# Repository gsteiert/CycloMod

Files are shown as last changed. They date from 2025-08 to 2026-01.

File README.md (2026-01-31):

# CycloMod
Cyclone 10LP plus RP2350 in SparkFun MicroMod form-factor

Be sure to subscribe to the [Cyclomod Crowd Supply Campaign](https://www.crowdsupply.com/steiert-solutions/cyclomod) for updates on when and how to get CycloMod.

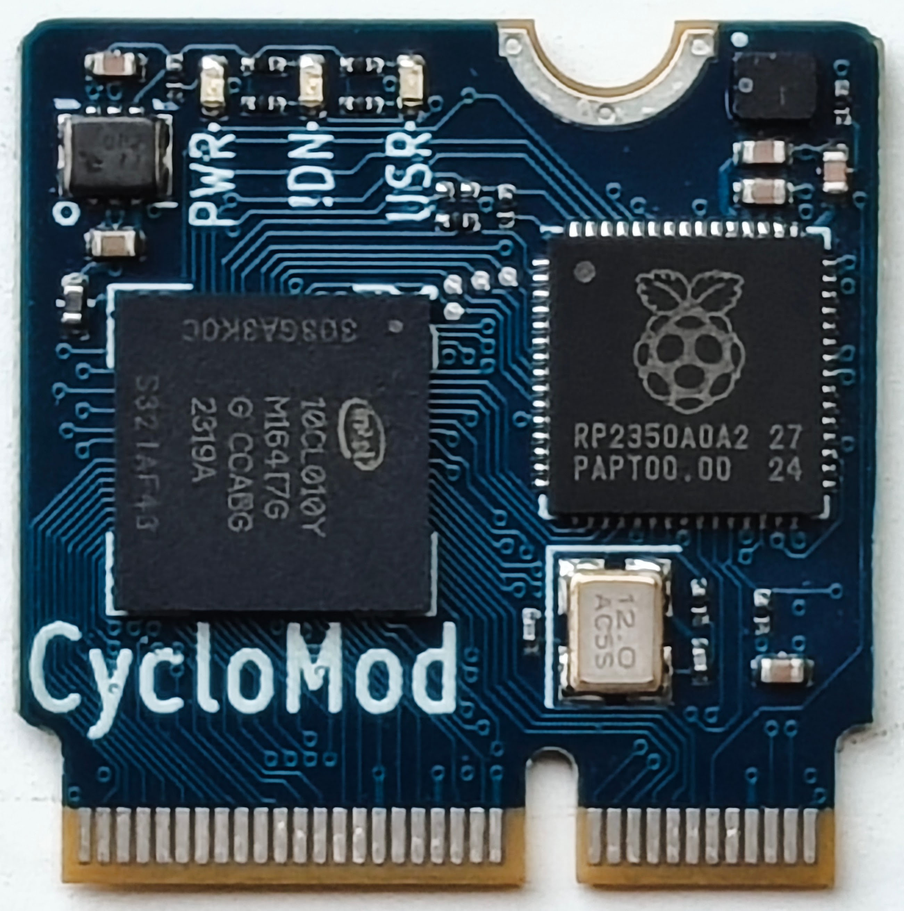
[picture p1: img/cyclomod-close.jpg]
CycloMod Board


CycloMod brings the flexibility of an FPGA to the SparkFun MicroMod ecosystem.  It combines the Raspberry Pi RP2350 with the Altera Cyclone 10LP, in a compact, adaptable module.  

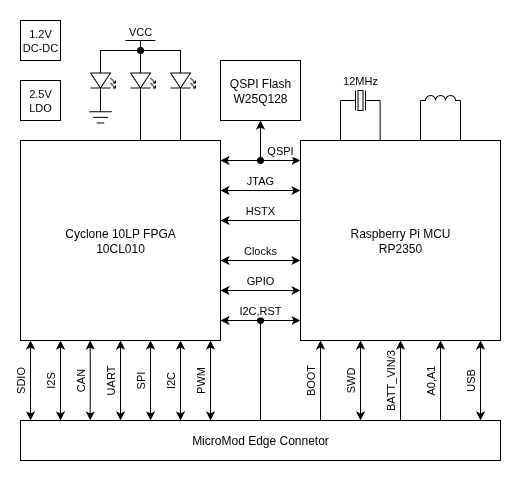
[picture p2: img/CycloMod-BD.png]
CycloMod Block Diagram


The FPGA and MCU are designed to be used together.  Most of the MicroMod I/O are connected to the FPGA for highest flexibility, while some functions like USB, ADC and SWD take advantage of the dedicated peripherals in the RP2350.  A few signals, like reset and the primary I2C bus, are connected to both devices.

Most of the RP2350 I/O are connected to Cyclone 10LP.  The MCU is connected to the JTAG pins of the FPGA so that the same flash can store the MCU firmware and FPGA images to be loaded with the Altera JBC player.  GPIO on the FPGA are connected to the MCU QSPI interface to provide a reasonable speed data path between the two devices.  The HSTX port is also connected for higher speed streaming from the MCU to the FPGA.  Input and Output clocks are also connected between the two devices to allow for sharing the 12MHz refernce crystal from the MCU and PLLs in the FPGA.  

The primary intended use case is for the RP2350 to manage the loading of the FPGA to eliminate the need for an additional storage device.  The active serial configuration pins are connected to the SPI port pins on the MicroMod card edge and there is a solder bridge selector that can be cut and shorted to enable laoding the FPGA from external SPI flash.

FPGA images can be transfered to flash over USB using the UF2 flash loader built into the RP2350 ROM.  Altera provides a [JAM Byte Code player](https://github.com/steieio/altera-jbc-player) that can be used to load the FPGA over JTAG.  A [script is available to combine the JBC file with the RP2350 firmware in a single UF2 file](https://github.com/steieio/jbcuf2).  This methodology was demonstrated in the ["Build a $5 FPGA loader" workshop at Crowd Supply Teardown 2024](https://www.crowdsupply.com/teardown/portland-2024/workshop/build-a-5-fpga-loader).

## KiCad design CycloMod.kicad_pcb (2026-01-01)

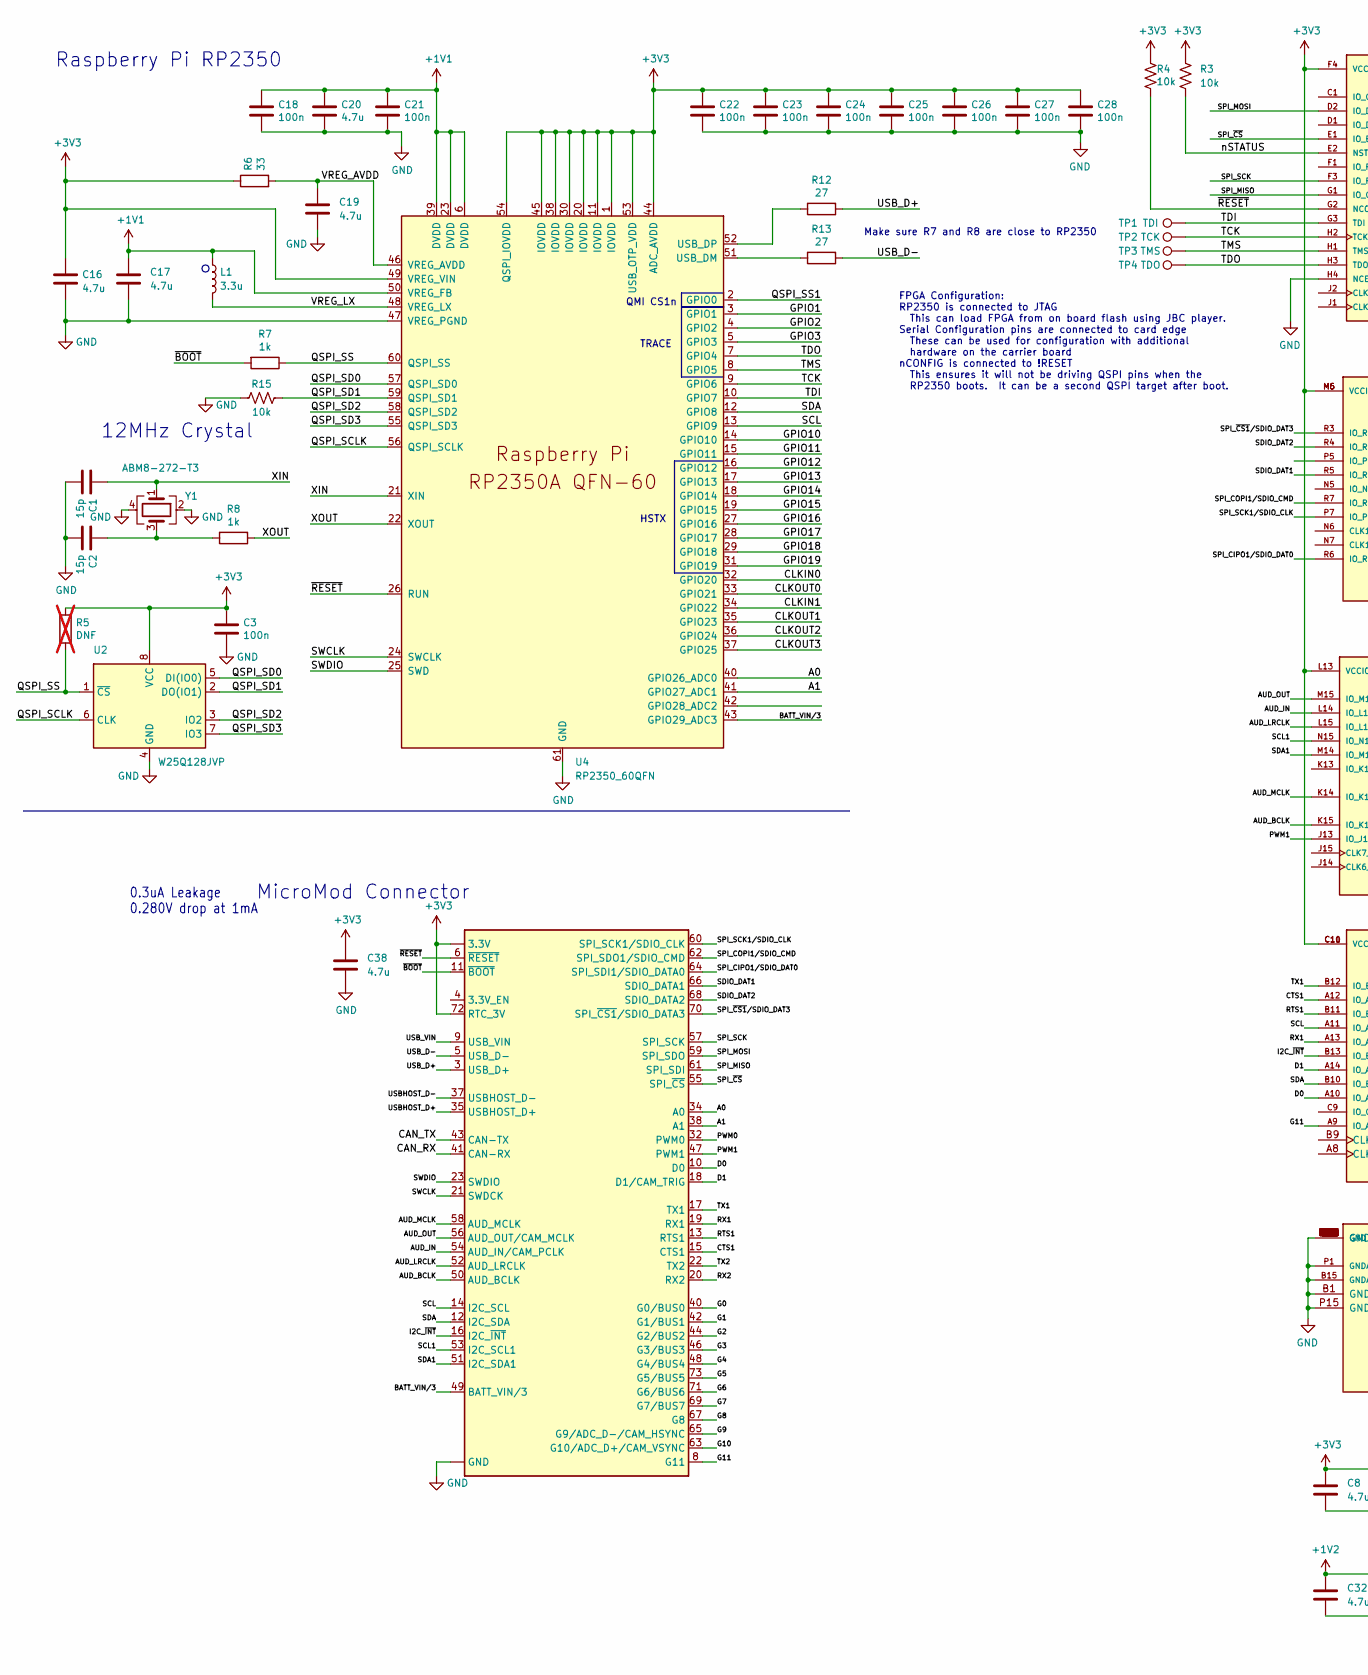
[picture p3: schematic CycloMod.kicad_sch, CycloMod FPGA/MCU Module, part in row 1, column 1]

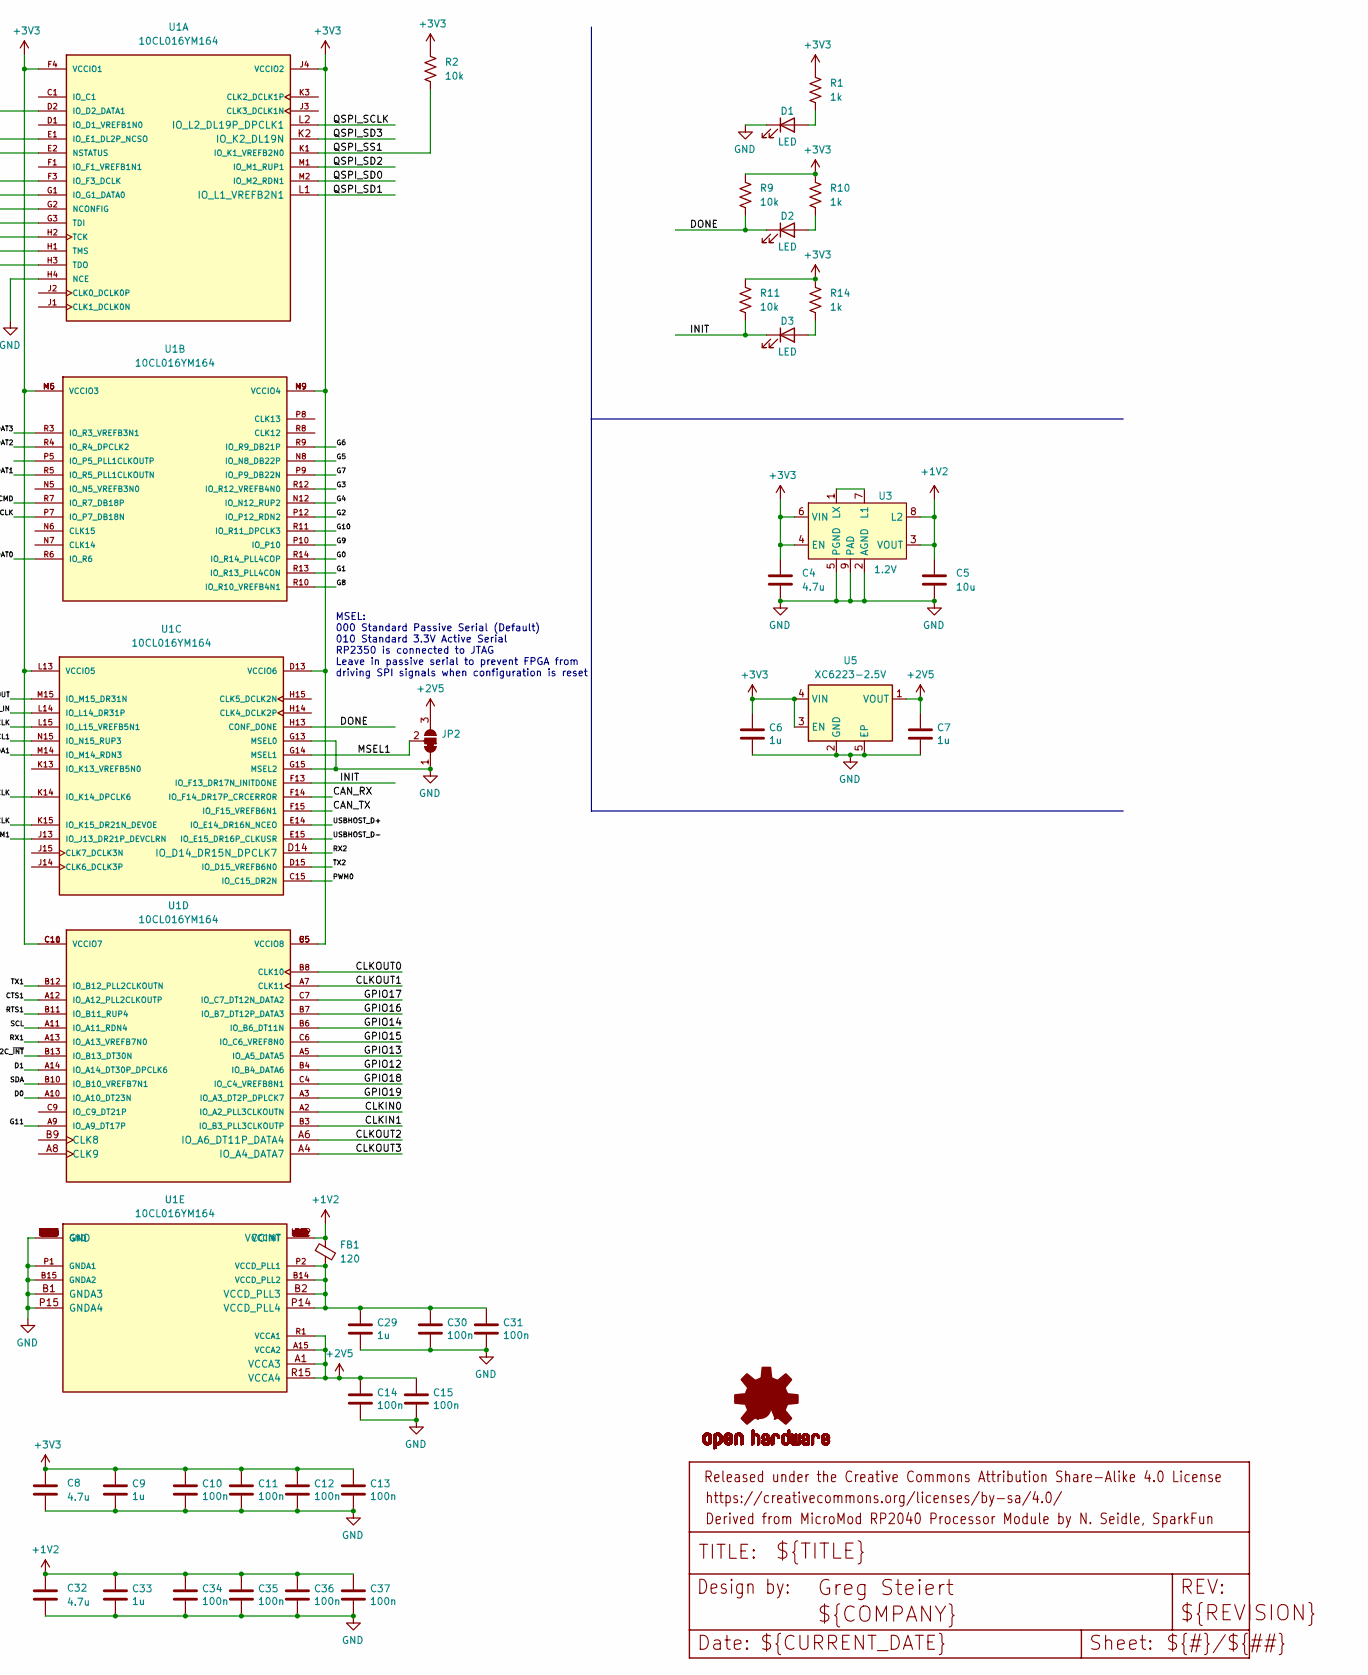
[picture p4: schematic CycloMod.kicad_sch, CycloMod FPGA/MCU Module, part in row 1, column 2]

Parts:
C1, C2: 15p; C_0201_0603Metric; MPN CC0201JRNPO9BN150; LCSC C277480
C3, C10, C11, C12, C13, C14, C15, C18, C21, C22, C23, C24, C25, C26, C27, C28, C30, C31, C34, C35, C36, C37: 100n; C_0201_0603Metric; MPN GRM033R61A104KE15D; LCSC C76934
C4, C8, C19, C20, C32, C38: 4.7u; C_0402_1005Metric; MPN CL05A475MQ5NRNC; LCSC C307423
C5: 10u; C_0402_1005Metric; MPN CL05A106MQ5NUNC; LCSC C15525
C6, C7, C9, C29, C33: 1u; C_0402_1005Metric; MPN CL05A105KP5NNNC; LCSC C14445
C16, C17: 4.7u; C_0402_1005Metric_small_pads; MPN CL05A475MQ5NRNC; LCSC C307423
D1, D2, D3: LED; LED_0402_1005Metric; MPN IN-S42BT5B; LCSC C6968967
FB1: 120; R_0402_1005Metric; MPN BLM15AG121SN1D; LCSC C85812
FRAME1: FRAME-LEDGER; CREATIVE_COMMONS
J1: MICROMOD-2222; MicroMod_Processor
JP2: SolderJumper_3_Bridged12; SolderJumper-3pin_Bridged_RoundedPad_0402
L1: 3.3u; L_pol_2016; MPN AOTA-B201610S3R3-101-T; LCSC C42411119
LOGO3: OSHW-LOGOMINI; OSHW-LOGO-MINI
R1, R7, R8, R10, R14: 1k; R_0201_0603Metric; MPN RC0201FR-071KL; LCSC C138165
R2, R3, R4, R9, R11, R15: 10k; R_0201_0603Metric; MPN RC0201FR-0710KL; LCSC C106225
R5: DNF; R_0201_0603Metric; not fitted
R6: 33; R_0201_0603Metric; MPN RC0201FR-0733RL; LCSC C295794
R12, R13: 27; R_0201_0603Metric; MPN RC0201FR-0727RL; LCSC C273268
TP1: TDI; TestPoint_Pad_D0.5mm
TP2: TCK; TestPoint_Pad_D0.5mm
TP3: TMS; TestPoint_Pad_D0.5mm
TP4: TDO; TestPoint_Pad_D0.5mm
U1: 10CL016YM164; M164_8.0x8.0mm_0.5mm; PARTREV 2019.03.29; LCSC C6063581
U2: W25Q128JVP; WSON-8-1EP_6x5mm_P1.27mm_EP3.4x4.3mm; MPN W25Q128JVPIQ; LCSC C190862
U3: 1.2V; CL-2025-02; MPN XCL239B123FR-G; LCSC C6036085
U4: RP2350_60QFN; RP2350-QFN-60-1EP_7x7_P0.4mm_EP3.4x3.4mm_ThermalVias; MPN RP2350A; LCSC C42411118
U5: XC6223-2.5V; UDFN-4-1EP_1x1mm_P0.65mm_EP0.48x0.48mm; MPN XC6233H2519R-G; LCSC C6934286
Y1: ABM8-272-T3; Crystal_SMD_3225-4Pin_3.2x2.5mm; MPN ABM8-272-T3; LCSC C20625731

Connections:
+1V1: C17.1, C18.1, C20.1, C21.1, L1.1, U4.6 (DVDD), U4.23 (DVDD), U4.39 (DVDD), U4.50 (VREG_FB)
+1V2: C5.1, C32.1, C33.1, C34.1, C35.1, C36.1, C37.1, FB1.1, U1.D3 (VCCINT), U1.D6 (VCCINT), U1.D8 (VCCINT), U1.D10 (VCCINT), U1.F12 (VCCINT), U1.H12 (VCCINT), U1.K12 (VCCINT), U1.L3 (VCCINT), U1.M8 (VCCINT), U1.M11 (VCCINT), U1.N2 (VCCINT), U1.P3 (VCCINT), U3.3 (VOUT), U3.8 (L2)
+2V5: C7.1, C14.1, C15.1, JP2.3 (B), U1.A1 (VCCA3), U1.A15 (VCCA2), U1.R1 (VCCA1), U1.R15 (VCCA4), U5.1 (VOUT)
+3V3: C3.1, C4.1, C6.1, C8.1, C9.1, C10.1, C11.1, C12.1, C13.1, C16.1, C22.1, C23.1, C24.1, C25.1, C26.1, C27.1, C28.1, C38.1, J1.2 (3.3V), J1.72 (RTC_3V), J1.74 (3.3V), R1.1, R2.1, R3.1, R4.1, R5.1, R6.1, R9.1, R10.1, R11.1, R14.1, U1.B5 (VCCIO8), U1.C5 (VCCIO8), U1.C10 (VCCIO7), U1.C11 (VCCIO7), U1.D13 (VCCIO6), U1.F4 (VCCIO1), U1.J4 (VCCIO2), U1.L13 (VCCIO5), U1.M5 (VCCIO3), U1.M6 (VCCIO3), U1.M9 (VCCIO4), U1.N9 (VCCIO4), U2.8 (VCC), U3.4 (EN), U3.6 (VIN), U4.1 (IOVDD), U4.11 (IOVDD), U4.20 (IOVDD), U4.30 (IOVDD), U4.38 (IOVDD), U4.44 (ADC_AVDD), U4.45 (IOVDD), U4.49 (VREG_VIN), U4.53 (USB_OTP_VDD), U4.54 (QSPI_IOVDD), U5.3 (EN), U5.4 (VIN)
/A0: J1.34 (A0), U4.40 (GPIO26_ADC0)
/A1: J1.38 (A1), U4.41 (GPIO27_ADC1)
/AUD_BCLK: J1.50 (AUD_BCLK), U1.K15 (IO_K15_DR21N_DEVOE)
/AUD_IN: J1.54 (AUD_IN/CAM_PCLK), U1.L14 (IO_L14_DR31P)
/AUD_LRCLK: J1.52 (AUD_LRCLK), U1.L15 (IO_L15_VREFB5N1)
/AUD_MCLK: J1.58 (AUD_MCLK), U1.K14 (IO_K14_DPCLK6)
/AUD_OUT: J1.56 (AUD_OUT/CAM_MCLK), U1.M15 (IO_M15_DR31N)
/BATT_VIN/3: J1.49 (BATT_VIN/3), U4.43 (GPIO29_ADC3)
/CAN_RX: J1.41 (CAN-RX), U1.F14 (IO_F14_DR17P_CRCERROR)
/CAN_TX: J1.43 (CAN-TX), U1.F15 (IO_F15_VREFB6N1)
/CLKIN0: U1.A2 (IO_A2_PLL3CLKOUTN), U4.32 (GPIO20)
/CLKIN1: U1.B3 (IO_B3_PLL3CLKOUTP), U4.34 (GPIO22)
/CLKOUT0: U1.B8 (CLK10), U4.33 (GPIO21)
/CLKOUT1: U1.A7 (CLK11), U4.35 (GPIO23)
/CLKOUT2: U1.A6 (IO_A6_DT11P_DATA4), U4.36 (GPIO24)
/CLKOUT3: U1.A4 (IO_A4_DATA7), U4.37 (GPIO25)
/CTS1: J1.15 (CTS1), U1.A12 (IO_A12_PLL2CLKOUTP)
/D0: J1.10 (D0), U1.A10 (IO_A10_DT23N)
/D1: J1.18 (D1/CAM_TRIG), U1.A14 (IO_A14_DT30P_DPCLK6)
/DONE: D2.1 (K), R9.2, U1.H13 (CONF_DONE)
/G0: J1.40 (G0/BUS0), U1.R14 (IO_R14_PLL4COP)
/G1: J1.42 (G1/BUS1), U1.R13 (IO_R13_PLL4CON)
/G2: J1.44 (G2/BUS2), U1.P12 (IO_P12_RDN2)
/G3: J1.46 (G3/BUS3), U1.R12 (IO_R12_VREFB4N0)
/G4: J1.48 (G4/BUS4), U1.N12 (IO_N12_RUP2)
/G5: J1.73 (G5/BUS5), U1.N8 (IO_N8_DB22P)
/G6: J1.71 (G6/BUS6), U1.R9 (IO_R9_DB21P)
/G7: J1.69 (G7/BUS7), U1.P9 (IO_P9_DB22N)
/G8: J1.67 (G8), U1.R10 (IO_R10_VREFB4N1)
/G9: J1.65 (G9/ADC_D-/CAM_HSYNC), U1.P10 (IO_P10)
/G10: J1.63 (G10/ADC_D+/CAM_VSYNC), U1.R11 (IO_R11_DPCLK3)
/G11: J1.8 (G11), U1.A9 (IO_A9_DT17P)
/GPIO1: U4.3 (GPIO1)
/GPIO2: U4.4 (GPIO2)
/GPIO3: U4.5 (GPIO3)
/GPIO10: U4.14 (GPIO10)
/GPIO11: U4.15 (GPIO11)
/GPIO12: U1.B4 (IO_B4_DATA6), U4.16 (GPIO12)
/GPIO13: U1.A5 (IO_A5_DATA5), U4.17 (GPIO13)
/GPIO14: U1.B6 (IO_B6_DT11N), U4.18 (GPIO14)
/GPIO15: U1.C6 (IO_C6_VREF8N0), U4.19 (GPIO15)
/GPIO16: U1.B7 (IO_B7_DT12P_DATA3), U4.27 (GPIO16)
/GPIO17: U1.C7 (IO_C7_DT12N_DATA2), U4.28 (GPIO17)
/GPIO18: U1.C4 (IO_C4_VREFB8N1), U4.29 (GPIO18)
/GPIO19: U1.A3 (IO_A3_DT2P_DPLCK7), U4.31 (GPIO19)
/I2C_~INT: J1.16 (I2C_~INT), U1.B13 (IO_B13_DT30N)
/INIT: D3.1 (K), R11.2, U1.F13 (IO_F13_DR17N_INITDONE)
/MSEL1: JP2.2 (C), U1.G14 (MSEL1)
/PWM0: J1.32 (PWM0), U1.C15 (IO_C15_DR2N)
/PWM1: J1.47 (PWM1), U1.J13 (IO_J13_DR21P_DEVCLRN)
/QSPI_SCLK: U1.L2 (IO_L2_DL19P_DPCLK1), U2.6 (CLK), U4.56 (QSPI_SCLK)
/QSPI_SD0: U1.M2 (IO_M2_RDN1), U2.5 (DI(IO0)), U4.57 (QSPI_SD0)
/QSPI_SD1: R15.2, U1.L1 (IO_L1_VREFB2N1), U2.2 (DO(IO1)), U4.59 (QSPI_SD1)
/QSPI_SD2: U1.M1 (IO_M1_RUP1), U2.3 (IO2), U4.58 (QSPI_SD2)
/QSPI_SD3: U1.K2 (IO_K2_DL19N), U2.7 (IO3), U4.55 (QSPI_SD3)
/QSPI_SS: R5.2, R7.1, U2.1 (~CS), U4.60 (QSPI_SS)
/QSPI_SS1: R2.2, U1.K1 (IO_K1_VREFB2N0), U4.2 (GPIO0)
/RTS1: J1.13 (RTS1), U1.B11 (IO_B11_RUP4)
/RX1: J1.19 (RX1), U1.A13 (IO_A13_VREFB7N0)
/RX2: J1.20 (RX2), U1.D14 (IO_D14_DR15N_DPCLK7)
/SCL: J1.14 (I2C_SCL), U1.A11 (IO_A11_RDN4), U4.13 (GPIO9)
/SCL1: J1.53 (I2C_SCL1), U1.N15 (IO_N15_RUP3)
/SDA: J1.12 (I2C_SDA), U1.B10 (IO_B10_VREFB7N1), U4.12 (GPIO8)
/SDA1: J1.51 (I2C_SDA1), U1.M14 (IO_M14_RDN3)
/SDIO_DAT1: J1.66 (SDIO_DATA1), U1.R5 (IO_R5_PLL1CLKOUTN)
/SDIO_DAT2: J1.68 (SDIO_DATA2), U1.R4 (IO_R4_DPCLK2)
/SPI_CIPO1/SDIO_DAT0: J1.64 (SPI_SDI1/SDIO_DATA0), U1.R6 (IO_R6)
/SPI_COPI1/SDIO_CMD: J1.62 (SPI_SDO1/SDIO_CMD), U1.R7 (IO_R7_DB18P)
/SPI_MISO: J1.61 (SPI_SDI), U1.G1 (IO_G1_DATA0)
/SPI_MOSI: J1.59 (SPI_SDO), U1.D2 (IO_D2_DATA1)
/SPI_SCK: J1.57 (SPI_SCK), U1.F3 (IO_F3_DCLK)
/SPI_SCK1/SDIO_CLK: J1.60 (SPI_SCK1/SDIO_CLK), U1.P7 (IO_P7_DB18N)
/SPI_~CS1/SDIO_DAT3: J1.70 (SPI_~CS1/SDIO_DATA3), U1.R3 (IO_R3_VREFB3N1)
/SPI_~CS: J1.55 (SPI_~CS), U1.E1 (IO_E1_DL2P_NCSO)
/SWCLK: J1.21 (SWDCK), U4.24 (SWCLK)
/SWDIO: J1.23 (SWDIO), U4.25 (SWD)
/TCK: TP2.1, U1.H2 (TCK), U4.9 (GPIO6)
/TDI: TP1.1, U1.G3 (TDI), U4.10 (GPIO7)
/TDO: TP4.1, U1.H3 (TDO), U4.7 (GPIO4)
/TMS: TP3.1, U1.H1 (TMS), U4.8 (GPIO5)
/TX1: J1.17 (TX1), U1.B12 (IO_B12_PLL2CLKOUTN)
/TX2: J1.22 (TX2), U1.D15 (IO_D15_VREFB6N0)
/USBHOST_D+: J1.35 (USBHOST_D+), U1.E14 (IO_E14_DR16N_NCEO)
/USBHOST_D-: J1.37 (USBHOST_D-), U1.E15 (IO_E15_DR16P_CLKUSR)
/USB_D+: J1.3 (USB_D+), R12.1
/USB_D-: J1.5 (USB_D-), R13.1
/USB_VIN: J1.9 (USB_VIN)
/VREG_AVDD: C19.1, R6.2, U4.46 (VREG_AVDD)
/VREG_LX: L1.2, U4.48 (VREG_LX)
/XIN: C1.1, U4.21 (XIN), Y1.1
/XOUT: R8.1, U4.22 (XOUT)
/nSTATUS: R3.2, U1.E2 (NSTATUS)
/~BOOT: J1.11 (~BOOT), R7.2
/~RESET: J1.6 (~RESET), R4.2, U1.G2 (NCONFIG), U4.26 (RUN)
GND: C1.2, C2.2, C3.2, C4.2, C5.2, C6.2, C7.2, C8.2, C9.2, C10.2, C11.2, C12.2, C13.2, C14.2, C15.2, C16.2, C17.2, C18.2, C19.2, C20.2, C21.2, C22.2, C23.2, C24.2, C25.2, C26.2, C27.2, C28.2, C29.2, C30.2, C31.2, C32.2, C33.2, C34.2, C35.2, C36.2, C37.2, C38.2, D1.1 (K), J1.1 (GND), J1.7 (GND), J1.33 (GND), J1.36 (GND), J1.39 (GND), J1.45 (GND), J1.75 (GND), J1.GND, JP2.1 (A), R15.1, U1.B1 (GNDA3), U1.B15 (GNDA2), U1.C2 (GND), U1.C8 (GND), U1.C12 (GND), U1.C14 (GND), U1.D5 (GND), U1.D7 (GND), U1.D9 (GND), U1.D11 (GND), U1.E3 (GND), U1.E13 (GND), U1.F2 (GND), U1.G4 (GND), U1.G12 (GND), U1.G13 (MSEL0), U1.G15 (MSEL2), U1.H4 (NCE), U1.J12 (GND), U1.K4 (GND), U1.M3 (GND), U1.M7 (GND), U1.M10 (GND), U1.M13 (GND), U1.N1 (GND), U1.N4 (GND), U1.N10 (GND), U1.N11 (GND), U1.N14 (GND), U1.P1 (GNDA1), U1.P4 (GND), U1.P6 (GND), U1.P11 (GND), U1.P13 (GND), U1.P15 (GNDA4), U1.R2 (GND), U2.4 (GND), U3.2 (AGND), U3.5 (PGND), U3.9 (PAD), U4.47 (VREG_PGND), U4.61 (GND), U5.2 (GND), U5.5 (EP), Y1.2, Y1.4
unnamed: C2.1, R8.2, Y1.3
unnamed: D1.2 (A), R1.2
unnamed: D2.2 (A), R10.2
unnamed: D3.2 (A), R14.2
unnamed: C29.1, C30.1, C31.1, FB1.2, U1.B2 (VCCD_PLL3), U1.B14 (VCCD_PLL2), U1.P2 (VCCD_PLL1), U1.P14 (VCCD_PLL4)
unnamed: U3.1 (LX), U3.7 (L1)
unnamed: R13.2, U4.51 (USB_DM)
unnamed: R12.2, U4.52 (USB_DP)

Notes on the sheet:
MicroMod Connector
MSEL: 000 Standard Passive Serial (Default) 010 Standard 3.3V Active Serial RP2350 is connected to JTAG Leave in passive serial to prevent FPGA from driving SPI signals when configuration is reset
HSTX
0.3uA Leakage 0.280V drop at 1mA
Raspberry Pi RP2350
QMI CS1n
FPGA Configuration: RP2350 is connected to JTAG This can load FPGA from on board flash using JBC player. Serial Configuration pins are connected to card edge These can be used for configuration with additional hardware on the carrier board nCONFIG is connected to !RESET This ensures it will not be 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
Make sure R7 and R8 are close to RP2350
TRACE
12MHz Crystal

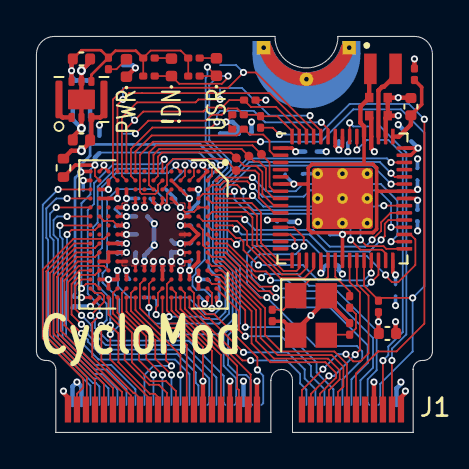
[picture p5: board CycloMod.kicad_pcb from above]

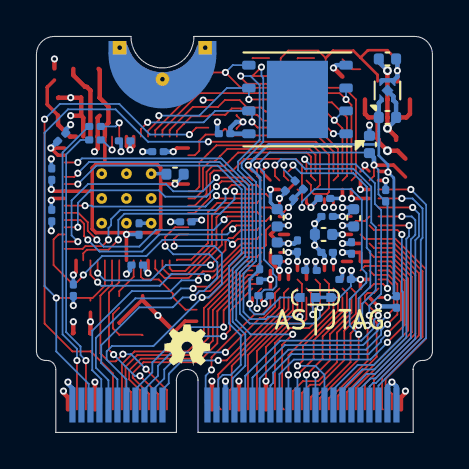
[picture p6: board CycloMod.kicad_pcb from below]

Board: 4 copper layers, 22.0 x 22.0 mm, 72 parts (37 on the bottom side), 101 nets.

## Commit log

2024-10-21 incremental edits
    [CycloMod.kicad_pcb, CycloMod.kicad_sch]
2024-10-26 signals connected, still need to place decoupling
    [CycloMod.kicad_pcb, CycloMod.kicad_sch]
2024-11-03 more routing and added decoupling caps for FPGA
    [CycloMod.kicad_pcb, CycloMod.kicad_sch]
2024-11-12 more cleanup, decoupling caps in, a couple nets need connecting, more cleanup to go
    [CycloMod.kicad_pcb, CycloMod.kicad_sch]
2024-11-28 checking in fully placed and routed. still needs silkscreen and cleanup
    [CycloMod.kicad_pcb, CycloMod.kicad_sch]
2024-12-23 started silkscreen cleanup, checking in prior to cardedge/outline update
    [CycloMod.kicad_pcb, CycloMod.kicad_sch]
2024-12-23 updated micromod footprint, more KiCad native
    [CycloMod.kicad_pcb]
2024-12-24 remaped QSPI pins, checking in before moving flash
    [CycloMod.kicad_pcb, CycloMod.kicad_sch]
2024-12-24 all connected, cleaning up
    [CycloMod.kicad_pcb, CycloMod.kicad_sch]
2024-12-25 cleaning up nets
    [CycloMod.kicad_pcb, CycloMod.kicad_sch]
2024-12-25 cleaned up some DRC, modified mechanical mounting half hole
    [CycloMod.kicad_pcb]
2025-07-30 commiting as submitted for build
    [CycloMod.kicad_pcb, CycloMod.kicad_sch]
2026-01-01 fixed QMI SD1 pull-down, cleaned up notes
    [CycloMod.kicad_pcb, CycloMod.kicad_sch]
2026-01-01 fixed BOM and re-sync to pcb
    [CycloMod.kicad_pcb, CycloMod.kicad_sch]
2026-01-01 Turned off resistor silkscreen for R15
    [CycloMod.kicad_pcb]
2026-01-25 moved block diagram to new img directory and added picture of board

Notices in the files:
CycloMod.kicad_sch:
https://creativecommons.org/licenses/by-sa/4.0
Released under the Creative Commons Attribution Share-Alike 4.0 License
